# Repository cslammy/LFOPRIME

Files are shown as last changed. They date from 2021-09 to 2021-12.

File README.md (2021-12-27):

# LFOPRIME
Low Frequency Oscillator without a bunch of useless frills

For more information about this project, please see this blog post:
http://audiodiwhy.blogspot.com/2021/09/lfo-prime-reverse-engineering-my-own.html

In 2002 or so I designed a simple analog LFO for modular synth and desktop bench use. I never documented anything about it, but used it for several years.  
I reverse engineered my own work so here is what I ended up with.  The zip file is the gerber, for PAIA FRAC +15/-15.  
It can pretty easily be redone for SKIFF/Euro and +/- 12V, which I may attempt at some point.

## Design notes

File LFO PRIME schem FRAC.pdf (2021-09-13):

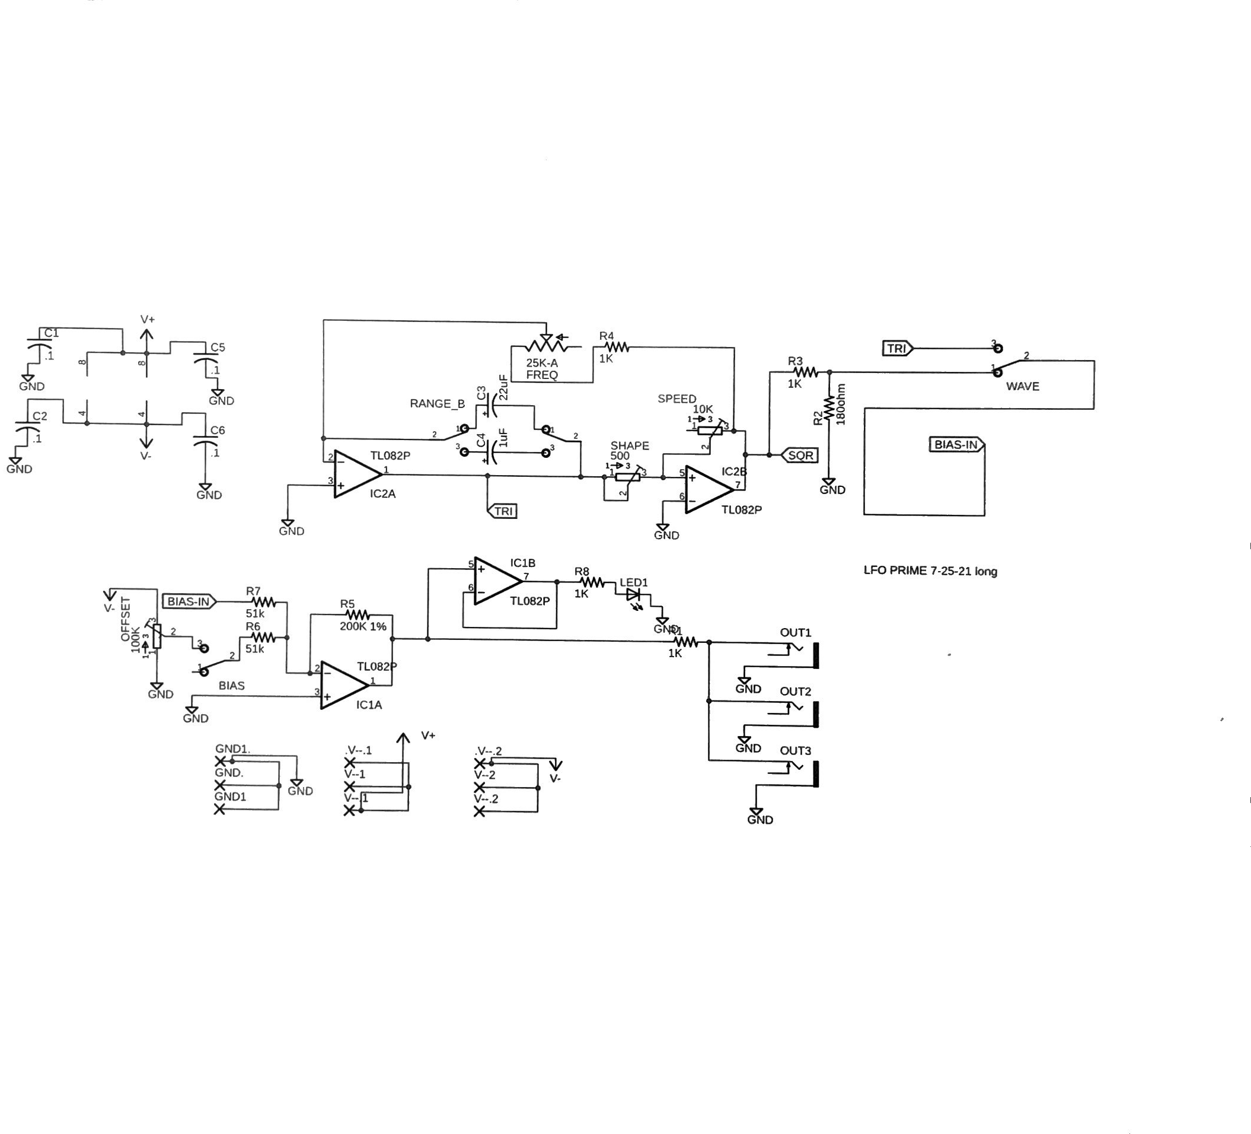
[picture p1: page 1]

Vt

a | cs a

GND
| GND
C2

*
rt | cé
ve | al
GND
| GND

LFO PRIME 7-25-21 tong

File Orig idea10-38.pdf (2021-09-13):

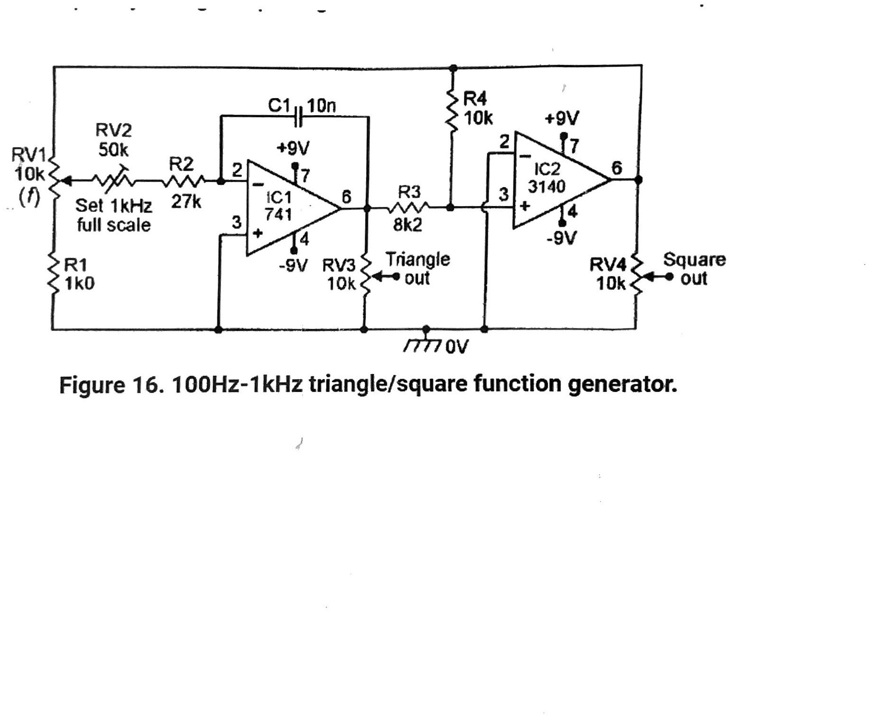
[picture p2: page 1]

Set 1kHz 27k
full scale
-9V RV3>_ | Triangle
mi | out 1kO

ov
Figure 16. 100Hz-1kHz triangle/square function generator.

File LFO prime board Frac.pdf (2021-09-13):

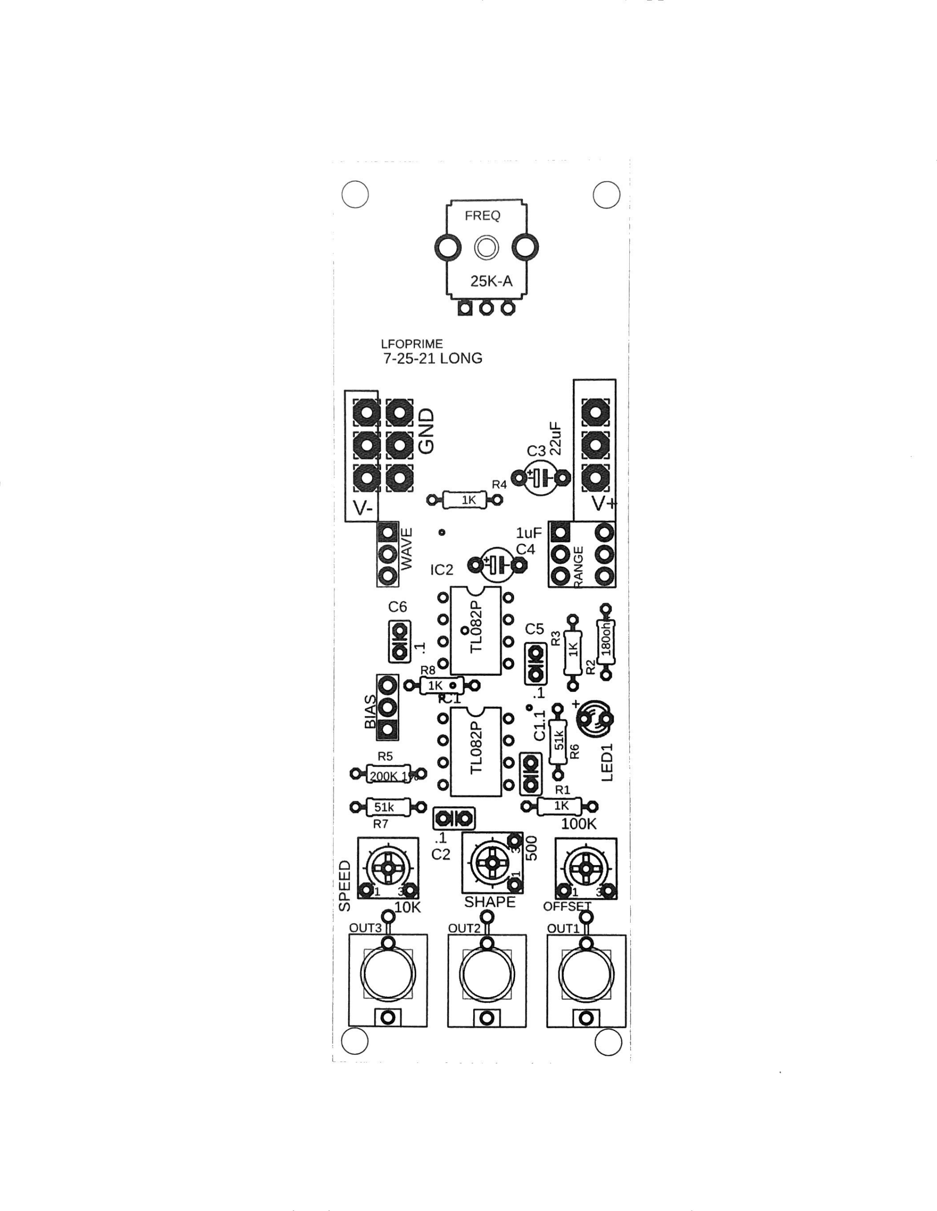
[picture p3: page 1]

OfET}O (Oy TON

## oft joaa

O08 j>

OFFS!
OUT1

006 OoGiate A lO)" 81 -

### cm @E9000 .. <ay

:

dzegU Q

dzs01L CE n

«a2

a | e soo8);| wo xT0008°

2
ONO
oway?Ey
ssOOS

°s

woe eeHe en)

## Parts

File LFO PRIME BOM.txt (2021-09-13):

Part   Value         Device           Package            Description                                        

C1     .1   25V         C-US025-025X050  C025-025X050       CAPACITOR, American symbol                                                                                              
C2     .1     25V       C-US025-025X050  C025-025X050       CAPACITOR, American symbol                                                                                              
C3     22uF     25V     CPOL-USE5-4      E5-4               POLARIZED CAPACITOR, American symbol                                                                                    
C4     1uF        25V   CPOL-USE5-4      E5-4               POLARIZED CAPACITOR, American symbol                                                                                    
C5     .1        25V    C-US025-025X050  C025-025X050       CAPACITOR, American symbol                                                                                              
C6     .1         25V    C-US025-025X050  C025-025X050       CAPACITOR, American symbol                                                                                              
FREQ   A25K          9MM_SNAP-IN_POT_ 9MM_SNAP-IN_POT    9mm vertical snap-in pot, Alpha / Panasonic style   .  One of these works.   
https://www.taydaelectronics.com/25k-ohm-linear-taper-potentiometer-round-shaft-pcb-9mm.html                                                                
 
IC1    TL082P        TL082P           DIL08              OP AMP                                              
IC2    TL082P        TL082P           DIL08              OP  AMP
LED1                 LED3MM           LED3MM             LED       (optional, any 3mm LED will work)                                                                                                              
OFFSET 100K          3362H            3362H              3362 Series  single turn 100K trim                                                                                                     
OUT1   THONKICONNNEW THONKICONNNEW    WQP-PJ301M-12_JACK 3.5mm socket for Eurorack modular synths                                                                                
OUT2   THONKICONNNEW THONKICONNNEW    WQP-PJ301M-12_JACK 3.5mm socket for Eurorack modular synths                                                                                
OUT3   THONKICONNNEW THONKICONNNEW    WQP-PJ301M-12_JACK 3.5mm socket for Eurorack modular synths      
resistors are 5% 1/4 watt through hole.                                                                          
R1     1K            R-US_0204/7      0204/7             RESISTOR, American symbol                                                                                               
R2     180ohm        R-US_0204/7      0204/7             RESISTOR, American symbol                                                                                               
R3     1K            R-US_0204/7      0204/7             RESISTOR, American symbol                                                                                               
R4     1K            R-US_0204/7      0204/7             RESISTOR, American symbol                                                                                               
R5     200K 1%       R-US_0204/7      0204/7             RESISTOR, American symbol                                                                                               
R6     50K           R-US_0204/7      0204/7             RESISTOR, American symbol                                                                                               
R7     50K           R-US_0204/7      0204/7             RESISTOR, American symbol                                                                                               
R8     1K            R-US_0204/7      0204/7             RESISTOR, American symbol        
Trimmer are bournes or bournes clones.                                                                                       
SHAPE  500           3362H            3362H              3362 Series  500ohm single turn trimmer                                                                                                       
SPEED  10K           3362H            3362H              3362 Series       10K single turn trimmer     
OFFSET 100K   3362H                                         3362 Series  100K single turn trimmer                                                                                                  

================
Switches: make sure to get ones that fit the PCB layout.
You will need 2x submini SPDT switches and 1x DPDT.
Here is what I used (current 9-13-21)
 
BIAS                 SPDTPADS         SPDT               TOGGLE SWITCH                                                                                                                                                                                                         
(and)
WAVE                 SPDTPADS         SPDT               TOGGLE SWITCH      https://m.made-in-china.com/product/for-Audio-Products-Spdt-Toggle-Switch-Latching-IP67-PCB-779020062.html       (or)
https://lovemyswitches.com/taiway-spdt-on-on-switch-pcb-long-shaft-non-threaded-bushing/                                                                                                 
RANGE                DPDT-WIDE        DPDT-WIDE    TAIWAY T2 submini DPDT pcb switch ; something like this.    
https://lovemyswitches.com/taiway-dpdt-on-on-switch-pcb-mount-short-shaft/

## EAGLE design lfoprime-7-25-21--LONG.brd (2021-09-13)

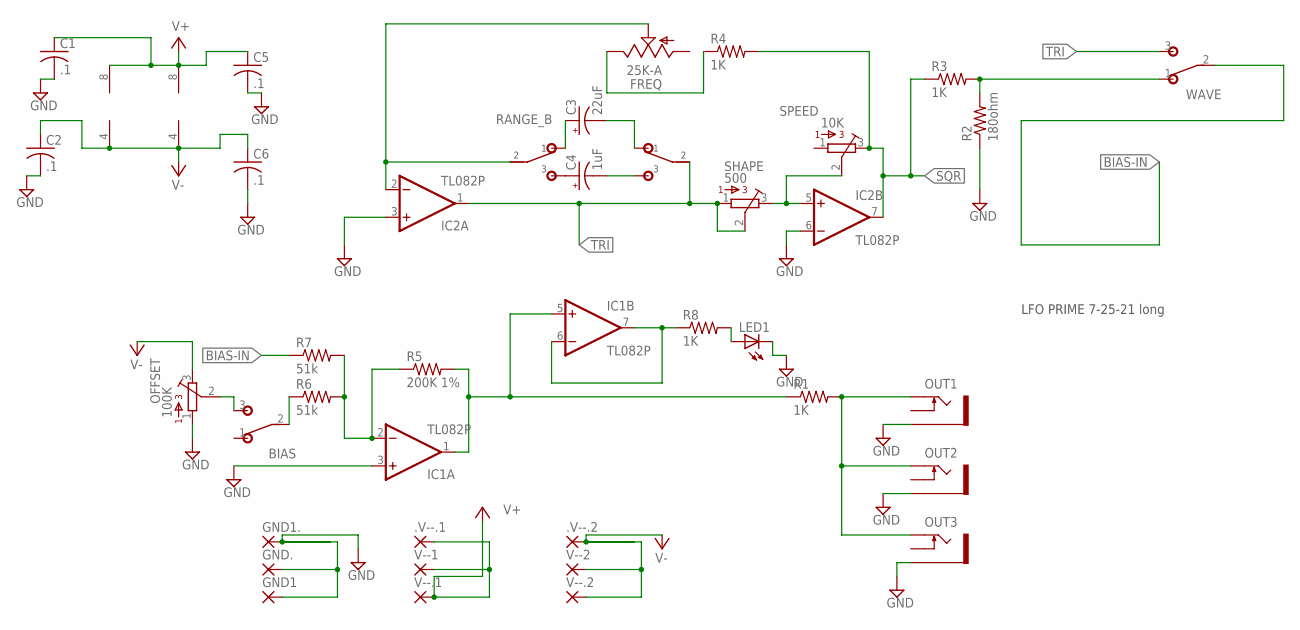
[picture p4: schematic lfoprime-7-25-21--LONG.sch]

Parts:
.V--.1, .V--.2: 3,17/1,3
BIAS: SPDTPADS; SPDT
C1, C2, C5, C6: .1; C025-025X050
C3: 22uF; E5-4
C4: 1uF; E5-4
FREQ: 25K-A; 9MM_SNAP-IN_POT
GND1, GND1., GND.: 3,17/1,3
IC1, IC2: TL082P; DIL08
LED1: LED3MM
OFFSET: 100K; 3362H
OUT1, OUT2, OUT3: THONKICONNNEW; WQP-PJ301M-12_JACK
R1, R3, R4, R8: 1K; 0204/7
R2: 180ohm; 0204/7
R5: 200K 1%; 0204/7
R6, R7: 51k; 0204/7
RANGE: DPDT-WIDE
SHAPE: 500; 3362H
SPEED: 10K; 3362H
V--1, V--2, V--.1, V--.2: 3,17/1,3
WAVE: SPDTPADS; SPDT

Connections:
BIAS-IN: R7.1, WAVE.2
BIAS-OUT: IC1.1 (OUT), IC1.5 (+IN), R1.1, R5.2
GND: C1.2, C2.2, C5.2, C6.2, GND1.1, GND1..1, GND..1, IC1.3 (+IN), IC2.3 (+IN), IC2.6 (-IN), LED1.K (C), OFFSET.1, OUT1.P$3_SLEEVE (SLEEVE), OUT2.P$3_SLEEVE (SLEEVE), OUT3.P$3_SLEEVE (SLEEVE), R2.1
unnamed: C4.+, RANGE.A3 (3)
unnamed: C4.-, RANGE.B3 (3)
unnamed: C3.+, RANGE.A1 (1)
unnamed: C3.-, RANGE.B1 (1)
unnamed: FREQ.2 (S), IC2.2 (-IN), RANGE.A2 (2)
unnamed: BIAS.3 (S), OFFSET.2
unnamed: IC2.5 (+IN), SHAPE.3, SPEED.2
unnamed: IC1.2 (-IN), R5.1, R6.2, R7.2
unnamed: IC1.6 (-IN), IC1.7 (OUT), R8.1
unnamed: OUT1.P$1_TIP (TIP), OUT2.P$1_TIP (TIP), OUT3.P$1_TIP (TIP), R1.2
unnamed: FREQ.3 (E), R4.1
unnamed: LED1.A, R8.2
unnamed: R2.2, R3.2, WAVE.1 (O)
unnamed: BIAS.2, R6.1
SQR: IC2.7 (OUT), R3.1, R4.2, SPEED.3
TRI: IC2.1 (OUT), RANGE.B2 (2), SHAPE.1, SHAPE.2, WAVE.3 (S)
V+: .V--.1.1, C1.1, C5.1, IC1.8 (V+), IC2.8 (V+), V--1.1, V--.1.1
V-: .V--.2.1, C2.1, C6.1, IC1.4 (V-), IC2.4 (V-), OFFSET.3, V--2.1, V--.2.1

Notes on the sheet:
LFO PRIME 7-25-21 long

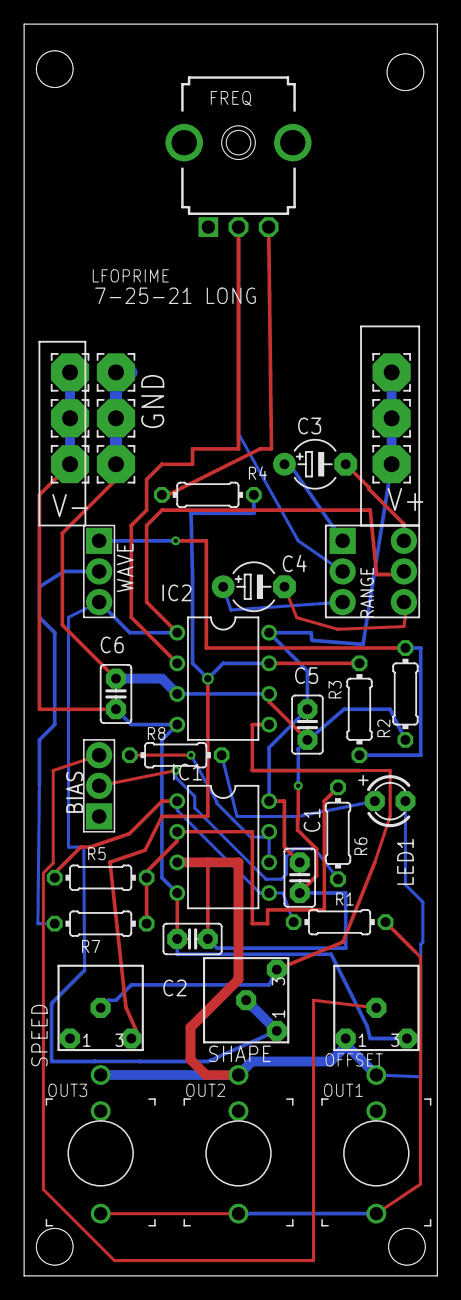
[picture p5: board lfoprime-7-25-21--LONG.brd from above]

Board: 2 copper layers, 34.3 x 103.8 mm, 36 parts (0 on the bottom side), 21 nets.
